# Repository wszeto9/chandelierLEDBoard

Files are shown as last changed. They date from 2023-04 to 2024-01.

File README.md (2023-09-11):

# Chandelier LED Board

A bright, addressible LED Panel that is used to light up a chandelier prop. Designed for MIT East Campus REX, Fall 2023.

[Interactive BOM](https://htmlpreview.github.io/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)

[PDF Schematic](https://github.com/wszeto9/chandelierLEDBoard/blob/7fa08e3c27c50bebdd73984cfcca761c36431bdc/Documentation/schematics.pdf)

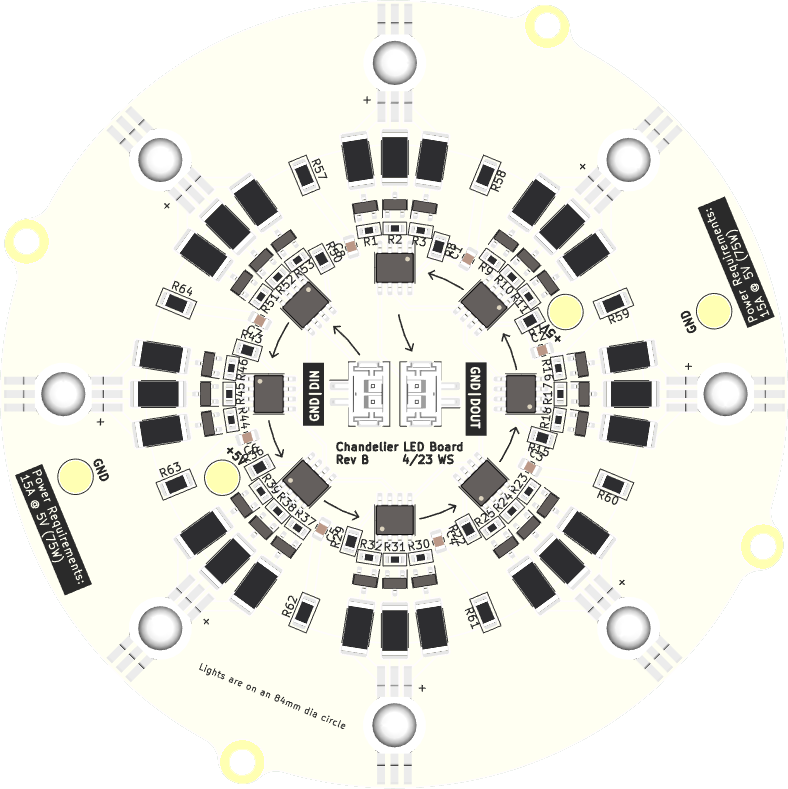
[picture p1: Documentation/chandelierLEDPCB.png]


<h2> Features:</h2>
<ul>
<li>Single layer stackup for an aluminum PCB to aid in thermal dissipation</li>
<li>8x 9W LEDs, for a total power of approximately 72W.
<li>LEDs are individually addressible, allowing for affects to be shown
<li>Daisy Chainable</li>
<li>Fits on an LGA1155 Cooler for easy cooling
</ul>

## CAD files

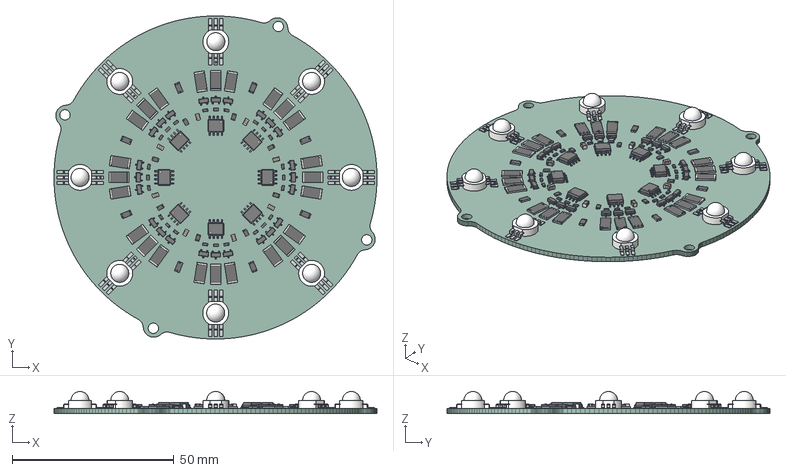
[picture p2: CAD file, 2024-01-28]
chandelierLEDPCB/chandelierLEDPCB.step
100.0 x 100.0 x 6.83 mm
_autosave-chandelierLEDPCB PCB

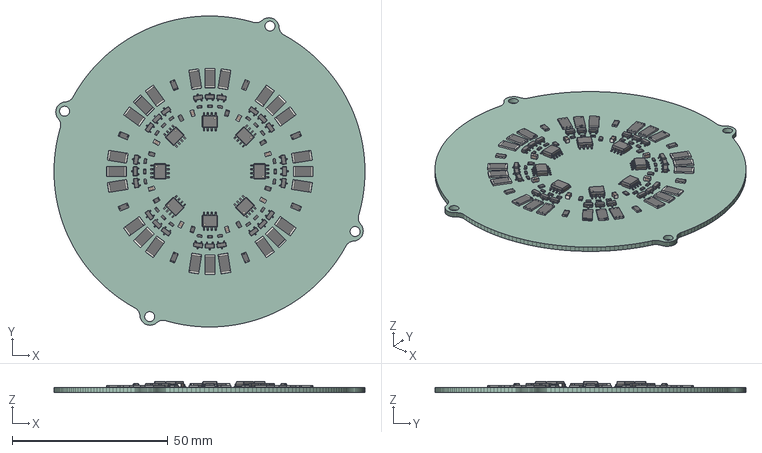
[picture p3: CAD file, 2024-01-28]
Documentation/chandelierLEDPCB.step
100.0 x 100.0 x 3.38 mm
_autosave-chandelierLEDPCB PCB

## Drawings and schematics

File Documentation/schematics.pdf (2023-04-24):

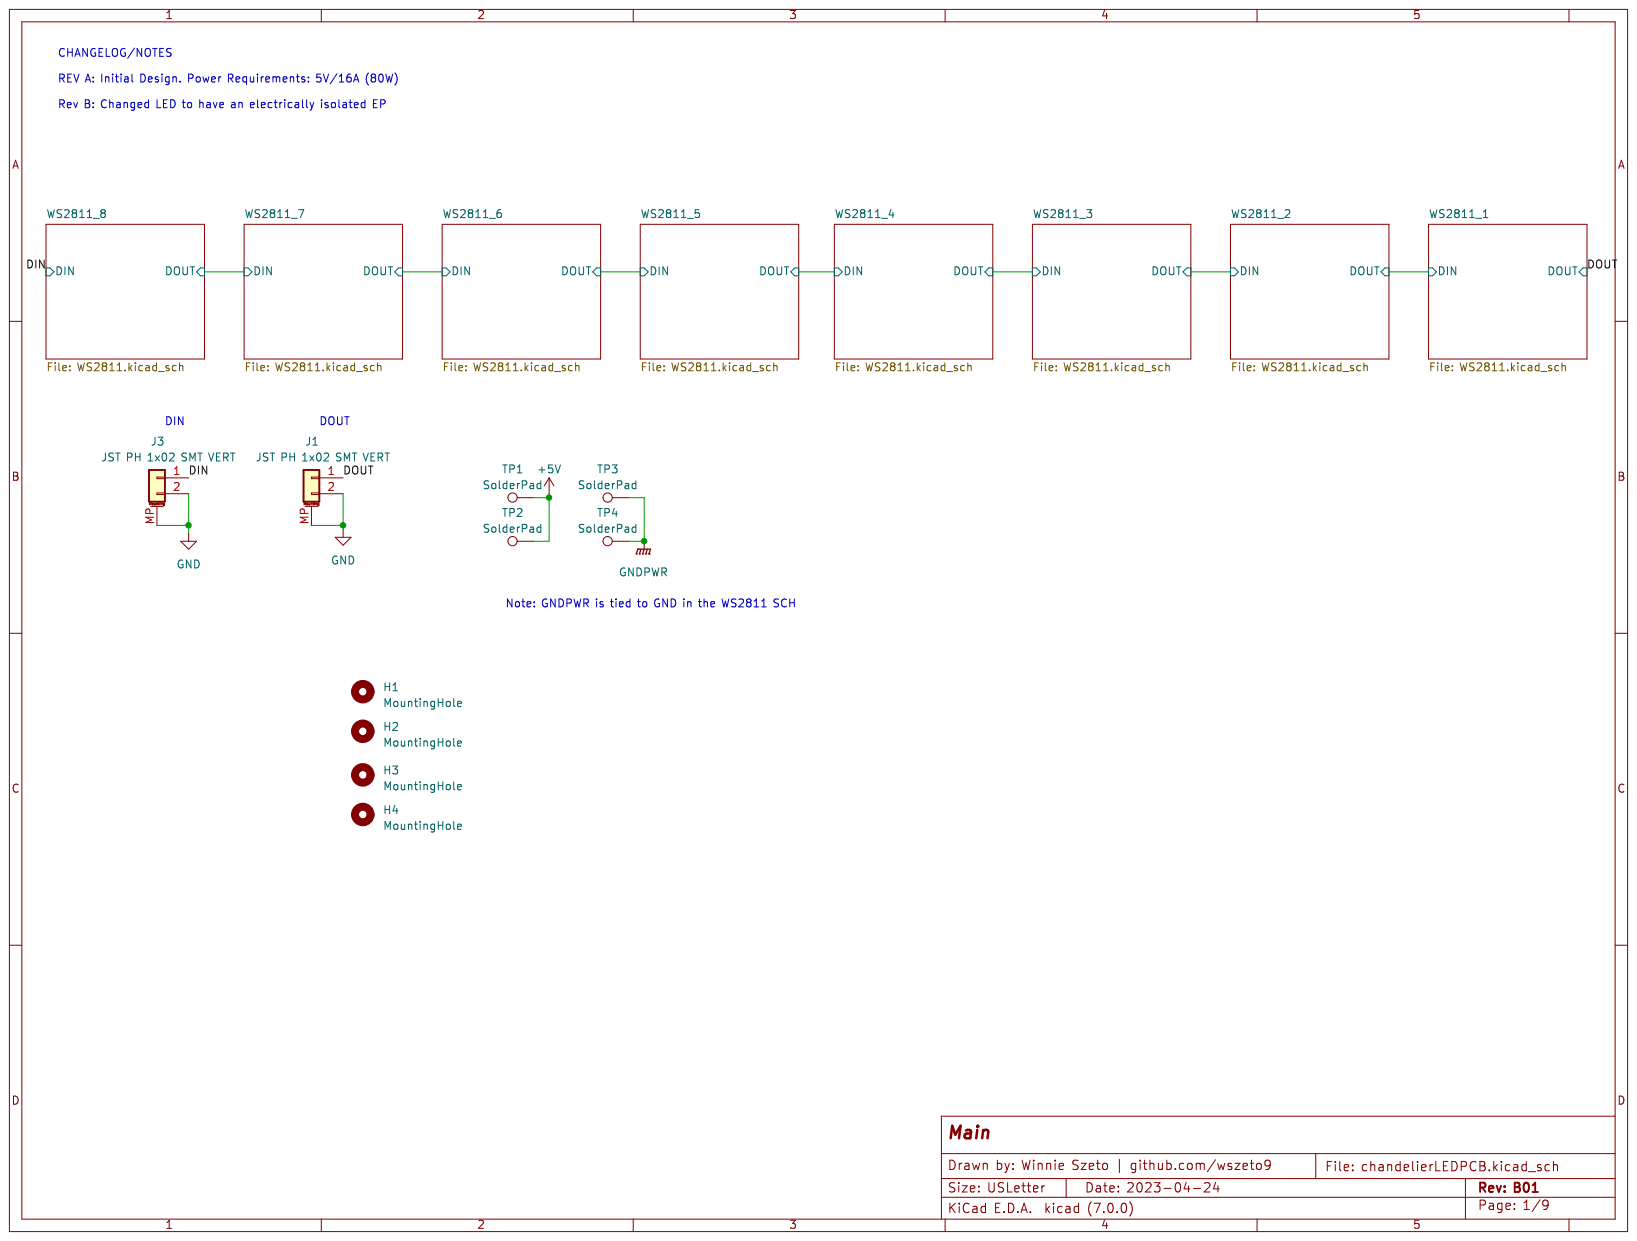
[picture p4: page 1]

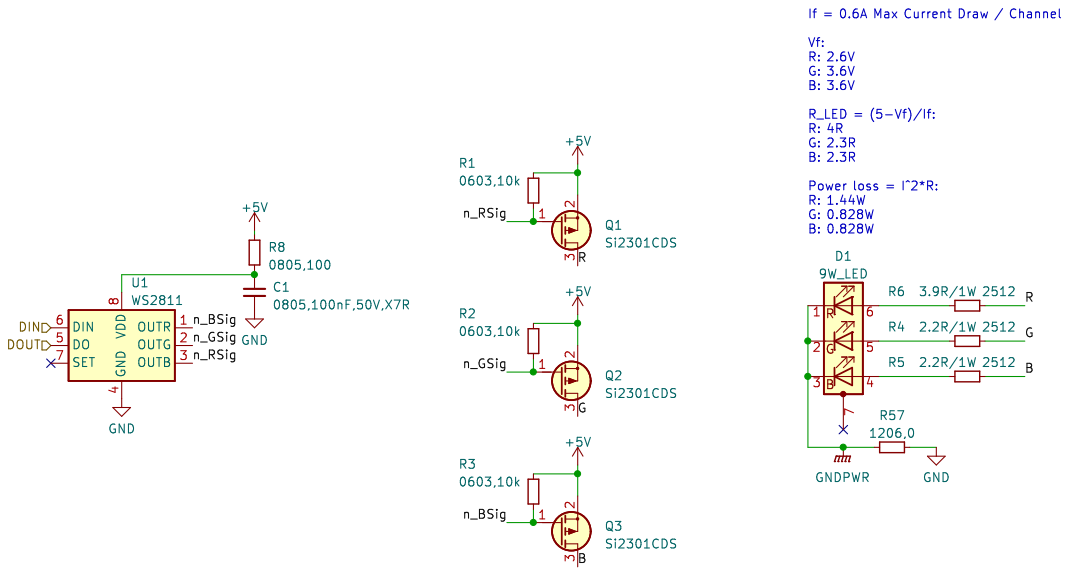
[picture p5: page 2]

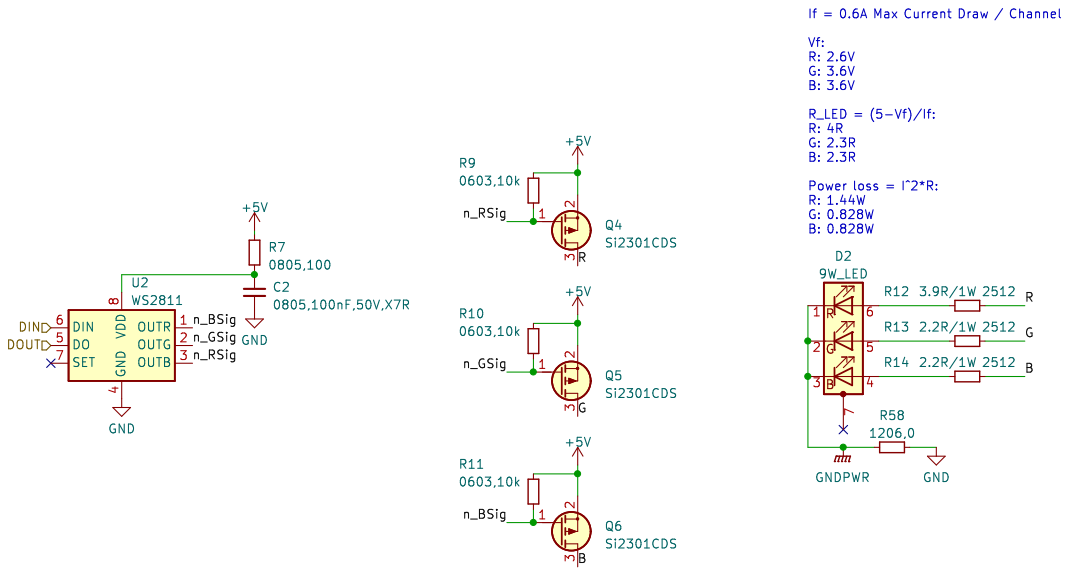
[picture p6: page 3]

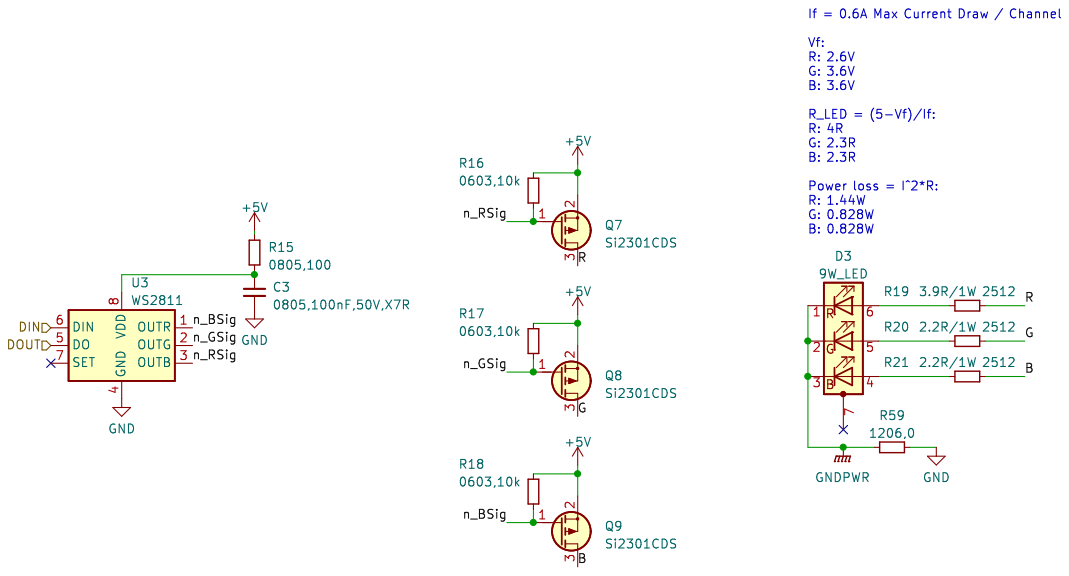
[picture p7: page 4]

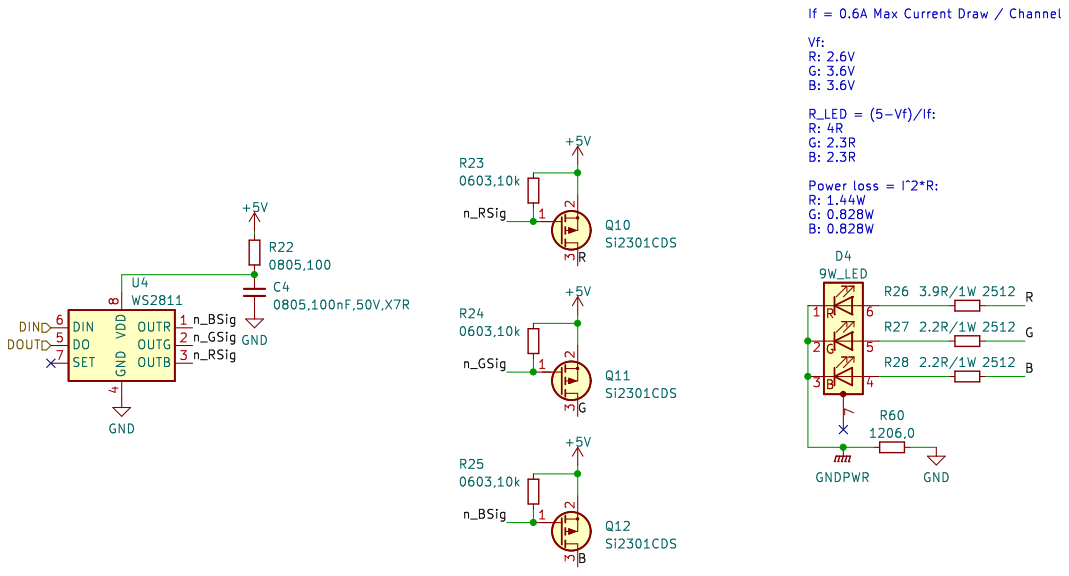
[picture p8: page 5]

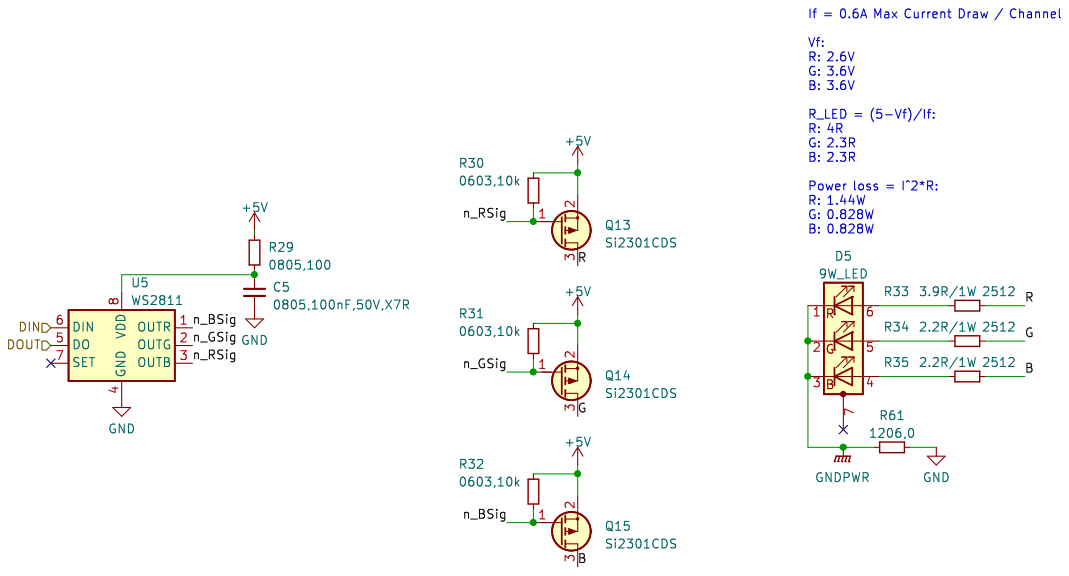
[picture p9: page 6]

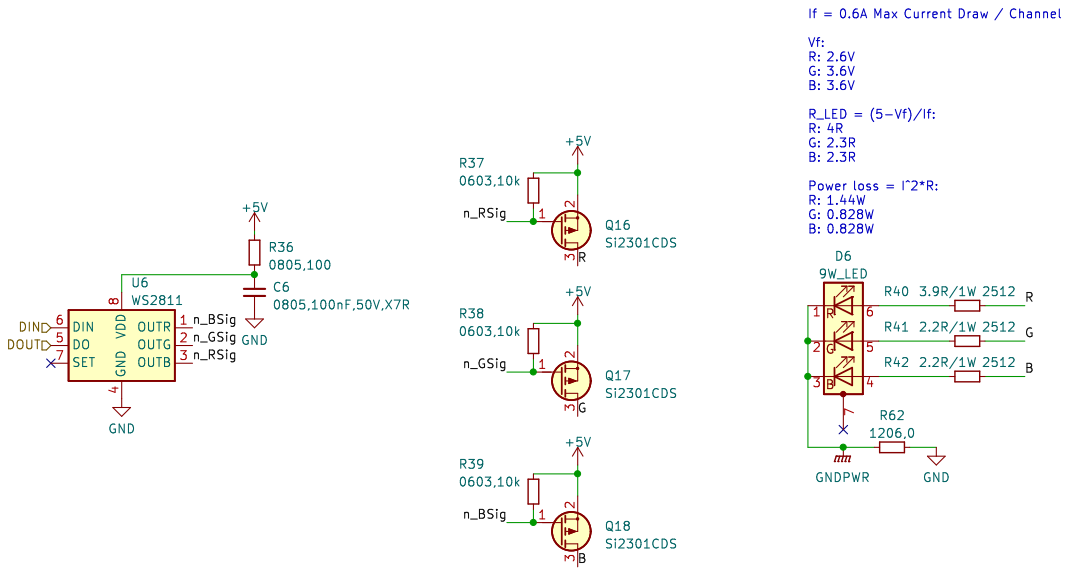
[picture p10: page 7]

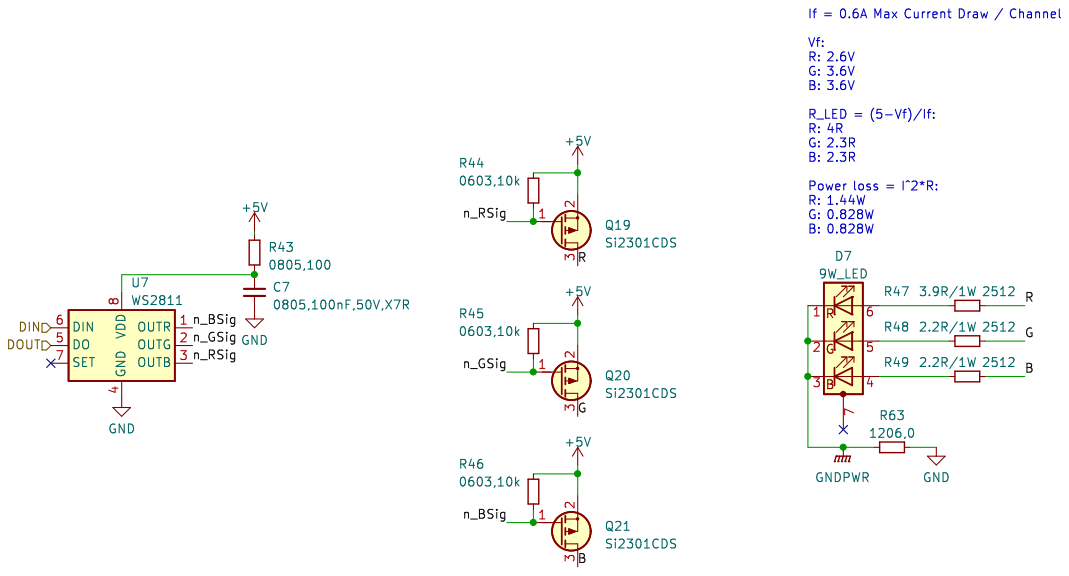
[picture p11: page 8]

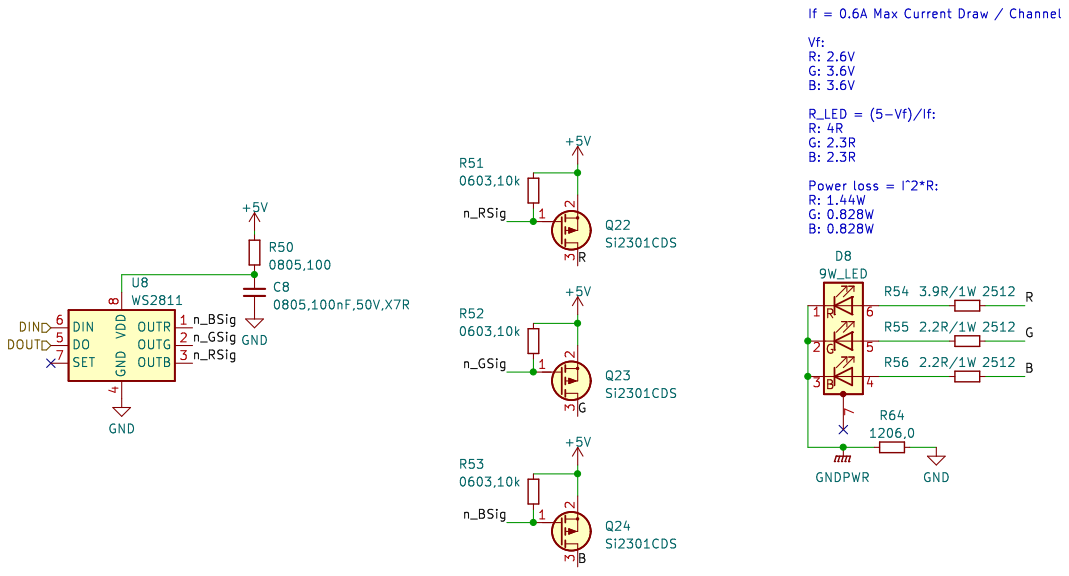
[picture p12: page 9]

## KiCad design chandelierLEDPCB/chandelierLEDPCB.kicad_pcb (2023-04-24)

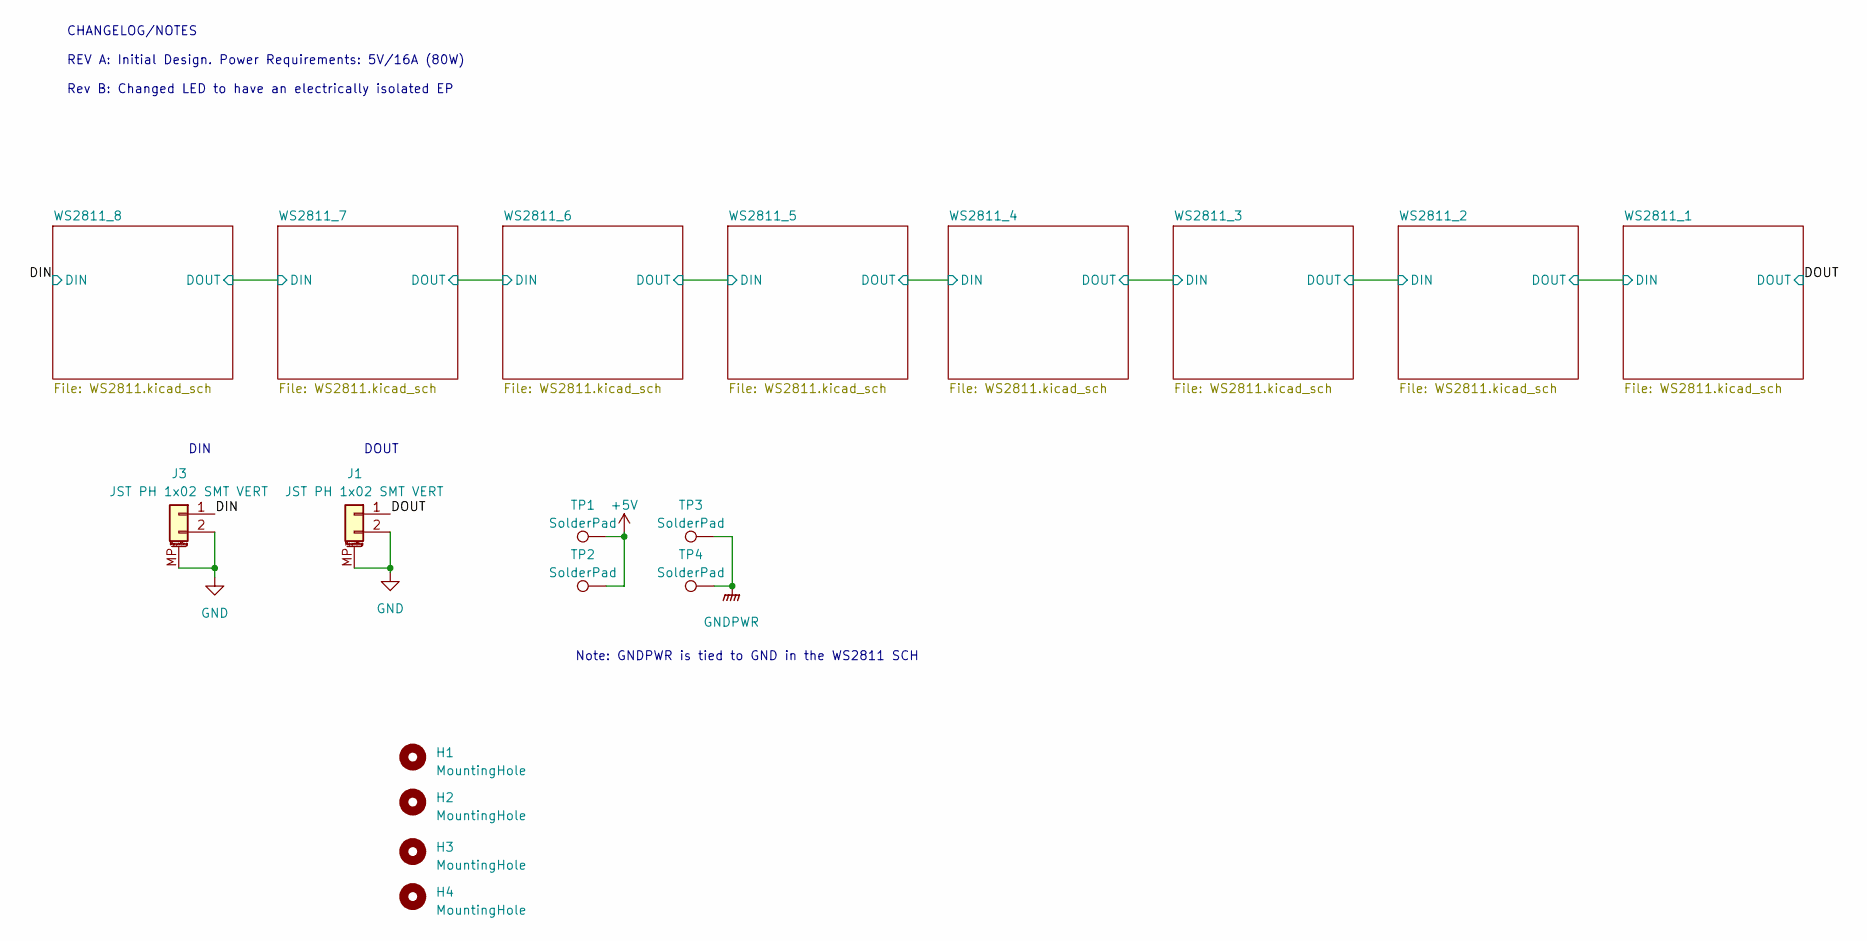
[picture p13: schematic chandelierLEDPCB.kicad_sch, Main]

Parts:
H1, H2, H3, H4: MountingHole; MountingHole_3.2mm_M3_DIN965_Pad_TopOnly
J1, J3: JST PH 1x02 SMT VERT; JST_PH_B2B-PH-SM4-TB_1x02-1MP_P2.00mm_Vertical
TP1, TP2, TP3, TP4: SolderPad; TestPoint_Pad_D4.0mm

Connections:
+5V: TP1.1, TP2.1; also elsewhere on the board
/DIN: J3.1; also elsewhere on the board
/DOUT: J1.1; also elsewhere on the board
GND: J1.2, J1.MP (MountPin), J3.2, J3.MP (MountPin); also elsewhere on the board
GNDPWR: TP3.1, TP4.1; also elsewhere on the board

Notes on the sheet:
Note: GNDPWR is tied to GND in the WS2811 SCH
DOUT
DIN
CHANGELOG/NOTES REV A: Initial Design. Power Requirements: 5V/16A (80W) Rev B: Changed LED to have an electrically isolated EP

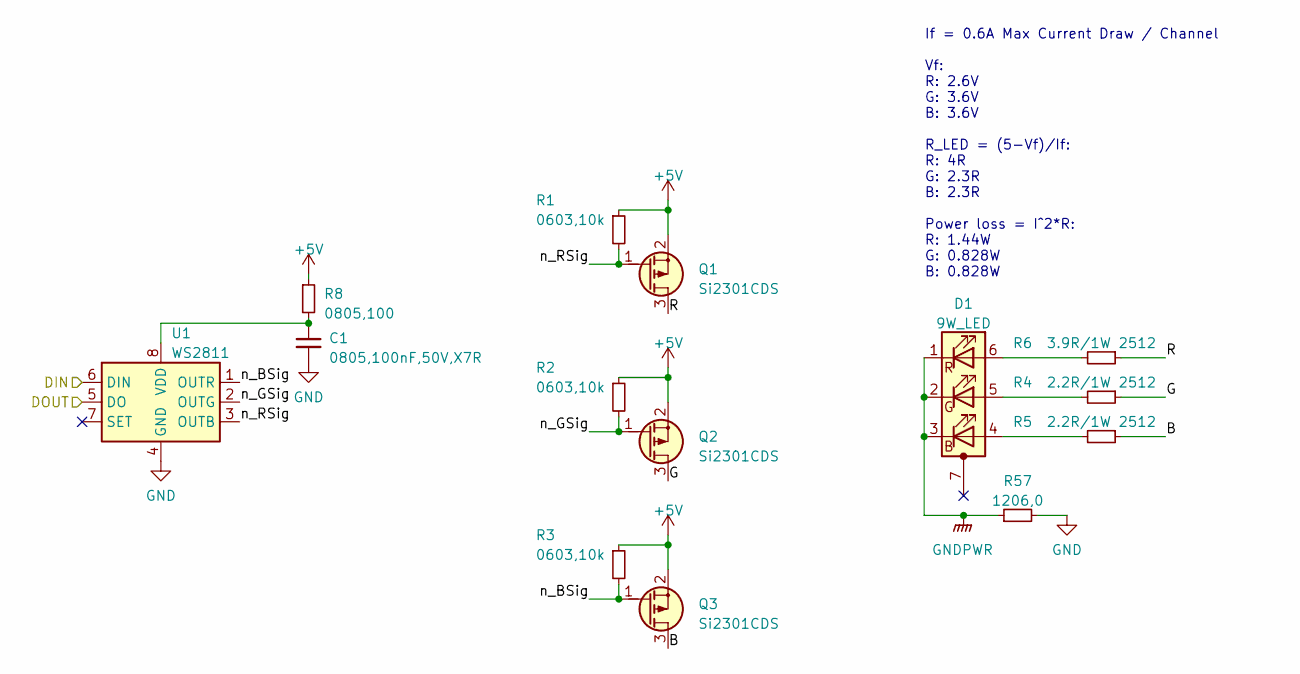
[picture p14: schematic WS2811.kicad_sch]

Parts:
C1: 0805,100nF,50V,X7R; C_0805_2012Metric; MFGPN CC0805KRX7R9BB104; LCSC C49678
D1: 9W_LED; 9WLED
Q1, Q2, Q3: Si2301CDS; SOT-23; LCSC C2891731
R1, R2, R3: 0603,10k; R_0603_1608Metric; MFGPN 0603WAF1002T5E; LCSC C25804
R4, R5: 2.2R/1W 2512; R_2512_6332Metric; LCSC C2907574
R6: 3.9R/1W 2512; R_2512_6332Metric; LCSC C2934114
R8: 0805,100; R_0805_2012Metric; MFGPN 0805W8F680JT5E; LCSC C17802
R57: 1206,0; R_1206_3216Metric; MFGPN 1206W4F0000T5E; LCSC C17888
U1: WS2811; SOIC-8_3.9x4.9mm_P1.27mm; LCSC C114581

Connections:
+5V: Q1.2 (S), Q2.2 (S), Q3.2 (S), R1.1, R2.1, R3.1, R8.1; also elsewhere on the board
/DOUT: U1.5 (DO); also elsewhere on the board
/WS2811_1/B: Q3.3 (D), R5.1
/WS2811_1/DIN: U1.6 (DIN); also elsewhere on the board
/WS2811_1/G: Q2.3 (D), R4.1
/WS2811_1/R: Q1.3 (D), R6.1
/WS2811_1/n_BSig: Q3.1 (G), R3.2, U1.1 (OUTR)
/WS2811_1/n_GSig: Q2.1 (G), R2.2, U1.2 (OUTG)
/WS2811_1/n_RSig: Q1.1 (G), R1.2, U1.3 (OUTB)
GND: C1.2, R57.2, U1.4 (GND); also elsewhere on the board
GNDPWR: D1.1 (RK), D1.2 (GK), D1.3 (BK), R57.1; also elsewhere on the board
unnamed: D1.4 (BA), R5.2
unnamed: D1.5 (GA), R4.2
unnamed: D1.6 (RA), R6.2
unnamed: C1.1, R8.2, U1.8 (VDD)

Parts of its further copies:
C2, C3, C4, C5, C6, C7, C8: 0805,100nF,50V,X7R; C_0805_2012Metric; MFGPN CC0805KRX7R9BB104; LCSC C49678
D2, D3, D4, D5, D6, D7, D8: 9W_LED; 9WLED
Q4, Q5, Q6, Q7, Q8, Q9, Q10, Q11, Q12, Q13, Q14, Q15, Q16, Q17, Q18, Q19, Q20, Q21, Q22, Q23, Q24: Si2301CDS; SOT-23; LCSC C2891731
R9, R10, R11, R16, R17, R18, R23, R24, R25, R30, R31, R32, R37, R38, R39, R44, R45, R46, R51, R52, R53: 0603,10k; R_0603_1608Metric; MFGPN 0603WAF1002T5E; LCSC C25804
R12, R19, R26, R33, R40, R47, R54: 3.9R/1W 2512; R_2512_6332Metric; LCSC C2934114
R13, R14, R20, R21, R27, R28, R34, R35, R41, R42, R48, R49, R55, R56: 2.2R/1W 2512; R_2512_6332Metric; LCSC C2907574
R58, R59, R60, R61, R62, R63, R64: 1206,0; R_1206_3216Metric; MFGPN 1206W4F0000T5E; LCSC C17888
U2, U3, U4, U5, U6, U7, U8: WS2811; SOIC-8_3.9x4.9mm_P1.27mm; LCSC C114581

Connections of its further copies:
+5V: Q4.2 (S), Q5.2 (S), Q6.2 (S), Q7.2 (S), Q8.2 (S), Q9.2 (S), Q10.2 (S), Q11.2 (S), Q12.2 (S), Q13.2 (S), Q14.2 (S), Q15.2 (S), Q16.2 (S), Q17.2 (S), Q18.2 (S), Q19.2 (S), Q20.2 (S), Q21.2 (S), Q22.2 (S), Q23.2 (S), Q24.2 (S), R9.1, R10.1, R11.1, R16.1, R17.1, R18.1, R23.1, R24.1, R25.1, R30.1, R31.1, R32.1, R37.1, R38.1, R39.1, R44.1, R45.1, R46.1, R51.1, R52.1, R53.1; also elsewhere on the board
/DIN: U8.6 (DIN); also elsewhere on the board
/WS2811_1/DIN: U2.5 (DO); also elsewhere on the board
/WS2811_2/B: Q6.3 (D), R14.1
/WS2811_2/DIN: U2.6 (DIN), U3.5 (DO)
/WS2811_2/G: Q5.3 (D), R13.1
/WS2811_2/R: Q4.3 (D), R12.1
/WS2811_2/n_BSig: Q6.1 (G), R11.2, U2.1 (OUTR)
/WS2811_2/n_GSig: Q5.1 (G), R10.2, U2.2 (OUTG)
/WS2811_2/n_RSig: Q4.1 (G), R9.2, U2.3 (OUTB)
/WS2811_3/B: Q9.3 (D), R21.1
/WS2811_3/DIN: U3.6 (DIN), U4.5 (DO)
/WS2811_3/G: Q8.3 (D), R20.1
/WS2811_3/R: Q7.3 (D), R19.1
/WS2811_3/n_BSig: Q9.1 (G), R18.2, U3.1 (OUTR)
/WS2811_3/n_GSig: Q8.1 (G), R17.2, U3.2 (OUTG)
/WS2811_3/n_RSig: Q7.1 (G), R16.2, U3.3 (OUTB)
/WS2811_4/B: Q12.3 (D), R28.1
/WS2811_4/DIN: U4.6 (DIN), U5.5 (DO)
/WS2811_4/G: Q11.3 (D), R27.1
/WS2811_4/R: Q10.3 (D), R26.1
/WS2811_4/n_BSig: Q12.1 (G), R25.2, U4.1 (OUTR)
/WS2811_4/n_GSig: Q11.1 (G), R24.2, U4.2 (OUTG)
/WS2811_4/n_RSig: Q10.1 (G), R23.2, U4.3 (OUTB)
/WS2811_5/B: Q15.3 (D), R35.1
/WS2811_5/DIN: U5.6 (DIN), U6.5 (DO)
/WS2811_5/G: Q14.3 (D), R34.1
/WS2811_5/R: Q13.3 (D), R33.1
/WS2811_5/n_BSig: Q15.1 (G), R32.2, U5.1 (OUTR)
/WS2811_5/n_GSig: Q14.1 (G), R31.2, U5.2 (OUTG)
/WS2811_5/n_RSig: Q13.1 (G), R30.2, U5.3 (OUTB)
/WS2811_6/B: Q18.3 (D), R42.1
/WS2811_6/DIN: U6.6 (DIN), U7.5 (DO)
/WS2811_6/G: Q17.3 (D), R41.1
/WS2811_6/R: Q16.3 (D), R40.1
/WS2811_6/n_BSig: Q18.1 (G), R39.2, U6.1 (OUTR)
/WS2811_6/n_GSig: Q17.1 (G), R38.2, U6.2 (OUTG)
/WS2811_6/n_RSig: Q16.1 (G), R37.2, U6.3 (OUTB)
/WS2811_7/B: Q21.3 (D), R49.1
/WS2811_7/DIN: U7.6 (DIN), U8.5 (DO)
/WS2811_7/G: Q20.3 (D), R48.1
/WS2811_7/R: Q19.3 (D), R47.1
/WS2811_7/n_BSig: Q21.1 (G), R46.2, U7.1 (OUTR)
/WS2811_7/n_GSig: Q20.1 (G), R45.2, U7.2 (OUTG)
/WS2811_7/n_RSig: Q19.1 (G), R44.2, U7.3 (OUTB)
/WS2811_8/B: Q24.3 (D), R56.1
/WS2811_8/G: Q23.3 (D), R55.1
/WS2811_8/R: Q22.3 (D), R54.1
/WS2811_8/n_BSig: Q24.1 (G), R53.2, U8.1 (OUTR)
/WS2811_8/n_GSig: Q23.1 (G), R52.2, U8.2 (OUTG)
/WS2811_8/n_RSig: Q22.1 (G), R51.2, U8.3 (OUTB)
GND: C2.2, C3.2, C4.2, C5.2, C6.2, C7.2, C8.2, R58.2, R59.2, R60.2, R61.2, R62.2, R63.2, R64.2, U2.4 (GND), U3.4 (GND), U4.4 (GND), U5.4 (GND), U6.4 (GND), U7.4 (GND), U8.4 (GND); also elsewhere on the board
GNDPWR: D2.1 (RK), D2.2 (GK), D2.3 (BK), D3.1 (RK), D3.2 (GK), D3.3 (BK), D4.1 (RK), D4.2 (GK), D4.3 (BK), D5.1 (RK), D5.2 (GK), D5.3 (BK), D6.1 (RK), D6.2 (GK), D6.3 (BK), D7.1 (RK), D7.2 (GK), D7.3 (BK), D8.1 (RK), D8.2 (GK), D8.3 (BK), R58.1, R59.1, R60.1, R61.1, R62.1, R63.1, R64.1; also elsewhere on the board
unnamed: D2.4 (BA), R14.2
unnamed: D2.5 (GA), R13.2
unnamed: D2.6 (RA), R12.2
unnamed: D3.4 (BA), R21.2
unnamed: D3.5 (GA), R20.2
unnamed: D3.6 (RA), R19.2
unnamed: D4.4 (BA), R28.2
unnamed: D4.5 (GA), R27.2
unnamed: D4.6 (RA), R26.2
unnamed: D5.4 (BA), R35.2
unnamed: D5.5 (GA), R34.2
unnamed: D5.6 (RA), R33.2
unnamed: D6.4 (BA), R42.2
unnamed: D6.5 (GA), R41.2
unnamed: D6.6 (RA), R40.2
unnamed: D7.4 (BA), R49.2
unnamed: D7.5 (GA), R48.2
unnamed: D7.6 (RA), R47.2
unnamed: D8.4 (BA), R56.2
unnamed: D8.5 (GA), R55.2
unnamed: D8.6 (RA), R54.2
unnamed 85: C2.1, U2.8 (VDD); also elsewhere on the board
unnamed 86: C3.1, U3.8 (VDD); also elsewhere on the board
unnamed 87: C4.1, U4.8 (VDD); also elsewhere on the board
unnamed 88: C5.1, U5.8 (VDD); also elsewhere on the board
unnamed 89: C6.1, U6.8 (VDD); also elsewhere on the board
unnamed 90: C7.1, U7.8 (VDD); also elsewhere on the board
unnamed 91: C8.1, U8.8 (VDD); also elsewhere on the board

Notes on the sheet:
If = 0.6A Max Current Draw / Channel Vf: R: 2.6V G: 3.6V B: 3.6V R_LED = (5-Vf)/If: R: 4R G: 2.3R B: 2.3R Power loss = I^2*R: R: 1.44W G: 0.828W B: 0.828W

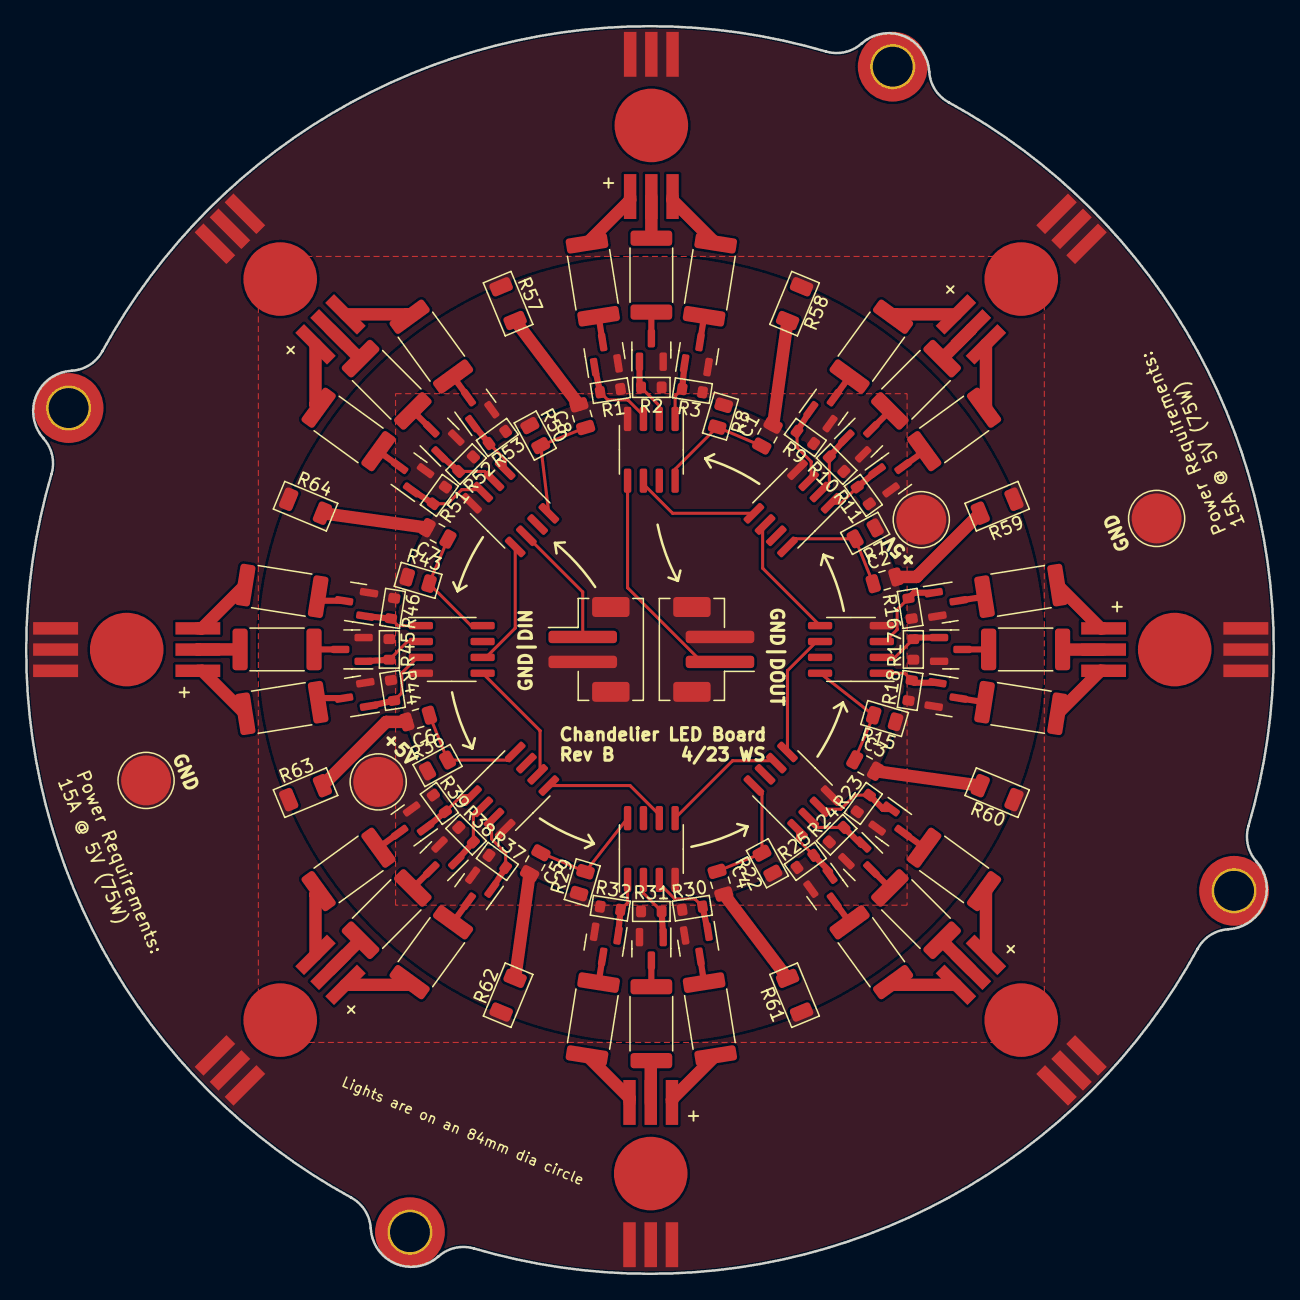
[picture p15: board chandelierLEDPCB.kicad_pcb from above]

Board: 2 copper layers, 100.0 x 100.0 mm, 122 parts (0 on the bottom side), 92 nets.

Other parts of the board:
R7, R15, R22, R29, R36, R43, R50: 0805,68; R_0805_2012Metric

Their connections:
+5V: R7.1, R15.1, R22.1, R29.1, R36.1, R43.1, R50.1; also elsewhere on the board
unnamed 85: R7.2; also elsewhere on the board
unnamed 86: R15.2; also elsewhere on the board
unnamed 87: R22.2; also elsewhere on the board
unnamed 88: R29.2; also elsewhere on the board
unnamed 89: R36.2; also elsewhere on the board
unnamed 90: R43.2; also elsewhere on the board
unnamed 91: R50.2; also elsewhere on the board

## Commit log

2023-04-02 Routed traces
    [WS2811.kicad_sch, chandelierLEDPCB.kicad_pcb, chandelierLEDPCB.kicad_sch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]
2023-04-08 Changed board outline
    [chandelierLEDPCB.kicad_pcb]
2023-04-08 updated schematic to include rev, edited sheet size
    [WS2811.kicad_sch, chandelierLEDPCB.kicad_sch]
2023-04-24 Added edge cuts and paste SVG for laser cutting stencil
    [chandelierLEDPCB.kicad_pcb]
2023-04-24 Edited LED to have EP disconnected
    [WS2811.kicad_sch, chandelierLEDPCB.kicad_pcb, chandelierLEDPCB.kicad_sch]
2024-01-28 cleaned up
    [chandelierLEDPCB.step]
